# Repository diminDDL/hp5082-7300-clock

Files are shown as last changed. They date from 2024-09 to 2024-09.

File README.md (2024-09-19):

# HP5082-7300 Clock

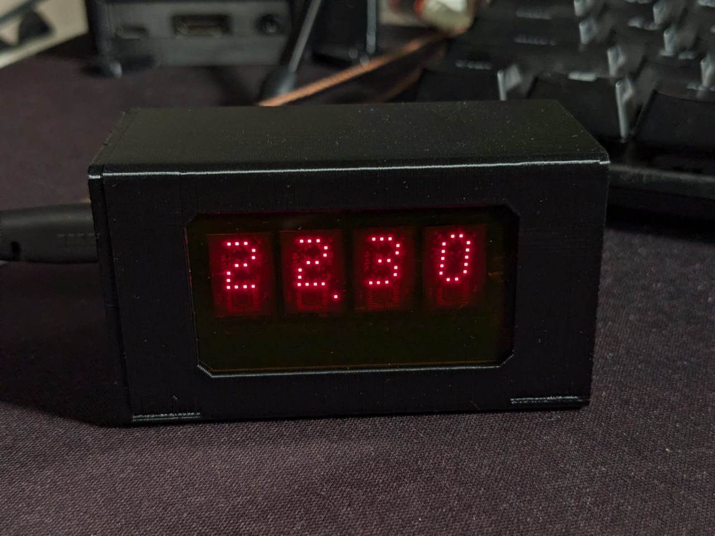
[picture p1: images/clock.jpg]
The finished clock


This repository contains the PlatformIO project for the Wemos D1 Mini based clock using the HP5082-7300 7-segment display. The repository also has the necessary 3D model files for the case. Since my case was designed around the protoboard I soldered the segments onto, it might not be compatible with your setup. Thus the Fusion 360 files as well as step files are included for you to modify.

## Features
- NTP time synchronization
- Timezone support
- DST support
- Web interface for configuration
- OTA updates*
 
*OTA updates are handled though the WiFiManager library, which requires you to upload a firmware file though the captive portal. You will need to remove the dummy OTA callback that is currently in the firmware for "security" reasons.

## Build instructions
### Hardware
- 1x Wemos D1 Mini
- 4x HP5082-7300 7-segment display
- 1x Button of any kind
- 1x 2k-100k pull-up resistor for the button
- 1x Thin sheet of plastic to protect the displays
- 2x 3.5M captive screws
- Protoboard, wires, etc.
- 3D printed case

#### Pinout
##### Segment Control Pins

These are the pins that select what to display on the display, the HP5082-7300 has it's own binary decoder and memory, meaning that we can wire all of these in parallel for all the segments and control the latching with the enable pins.

| Pin Number | Pin Name | Description |
|---|---|---|
| D1 | DIGIT_PIN_1 | Binary digit selection pin (LSB) |
| D2 | DIGIT_PIN_2 | Binary digit selection pin |
| D3 | DIGIT_PIN_4 | Binary digit selection pin |
| D4 | DIGIT_PIN_8 | Binary digit selection pin (MSB) |

##### Display Enable Pins

Each display in the 4x HP5082-7300 array is enabled individually using the following pins:

| Pin Number | Pin Name | Description |
|---|---|---|
| D8 | DIGIT_0_EN_PIN | Enables the digit 0 |
| D7 | DIGIT_1_EN_PIN | Enables the digit 1 |
| D6 | DIGIT_2_EN_PIN | Enables the digit 2 |
| D5 | DIGIT_3_EN_PIN | Enables the digit 3 |

##### Dot Pin

The dot is a decimal point that is pulsed once a second, it connected to the digit that separates the hours and minutes. Connect this to `D0`.

##### Button Pin

The button is connected to `A0` and it pulled up to 3.3V externally using the resistor. The button shorts the pin to ground when pressed. The analog pin is used because there were not enough pins on the Wemos D1 Mini to use a separate pin for the button.

### Software
1. Clone/Download the repository
2. Open the HP50827300Clock in [PlatformIO](https://marketplace.visualstudio.com/items?itemName=platformio.platformio-ide)
3. Change the `DST_REGION` to one of the following:
`DST_EUROPE`,
`DST_NORTH_AMERICA`,
`DST_AUSTRALIA`,
`DST_SOUTH_AMERICA`
4. Build and upload the firmware to the Wemos D1 Mini

## Usage
After the code is uploaded the clock will display `----` and create a WiFi network called `LED Clock Config`. You can use your phone to connect to this network and it should automatically open a configuration page.
- First, enter the `Setup` menu and configure your timezone and DST preference. You can leave the NTP server as is. Click `Save` and it should show a confirmation message.

If the page does not put you back to the main page you can manually go back until you reach it.

- Next enter the `Configure WiFi` menu (it will take a bit to open since it is scanning for networks). Click the network name you'd like to connect to and enter the password. Click `Save` and it should show a confirmation message.

Within a minute the clock should connect to the network and start displaying the time. If it doesn't the clock will keep displaying `----` and re-open the `LED Clock Config` access point for you to try configuring it again.

### Resetting

As mentioned before, when the clock can't connect to the WiFi network it will re-open the `LED Clock Config` access point. But if you want to reset it manually you can press and hold the button for 5 seconds. The clock will display an animation while you are holding the button and show `----` once it is reset, you can let go of the button at that point, and now use the access point to configure it again.

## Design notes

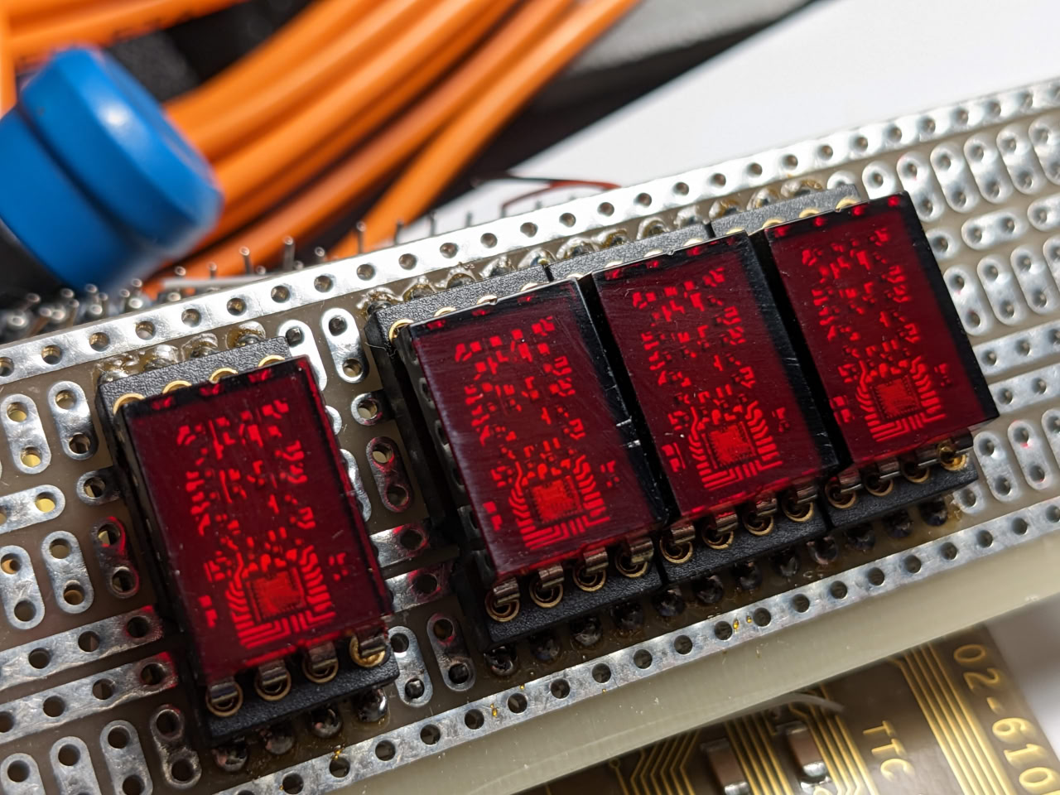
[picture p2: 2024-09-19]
images/panel.jpg

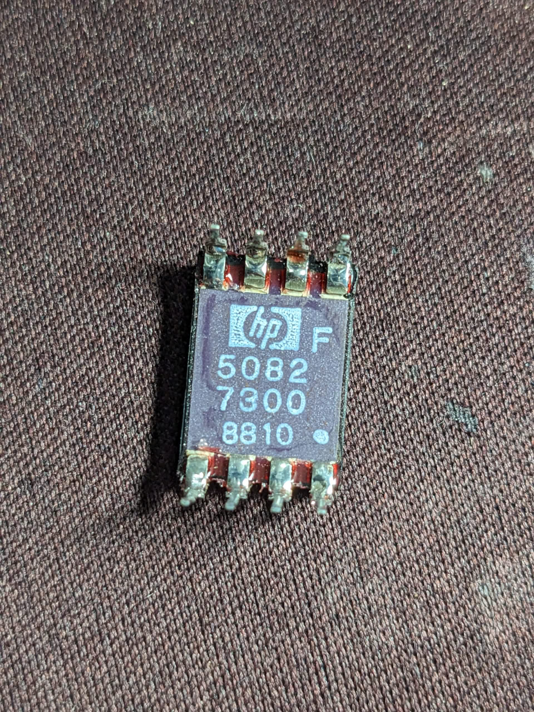
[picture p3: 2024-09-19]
images/indicator.jpg

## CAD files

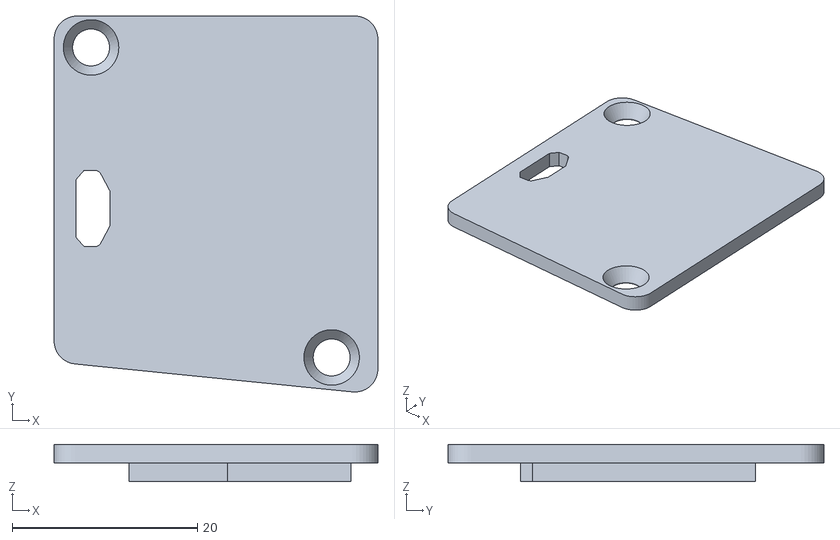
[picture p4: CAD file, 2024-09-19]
3D/clockCover.stl
35.0 x 40.6 x 4.00

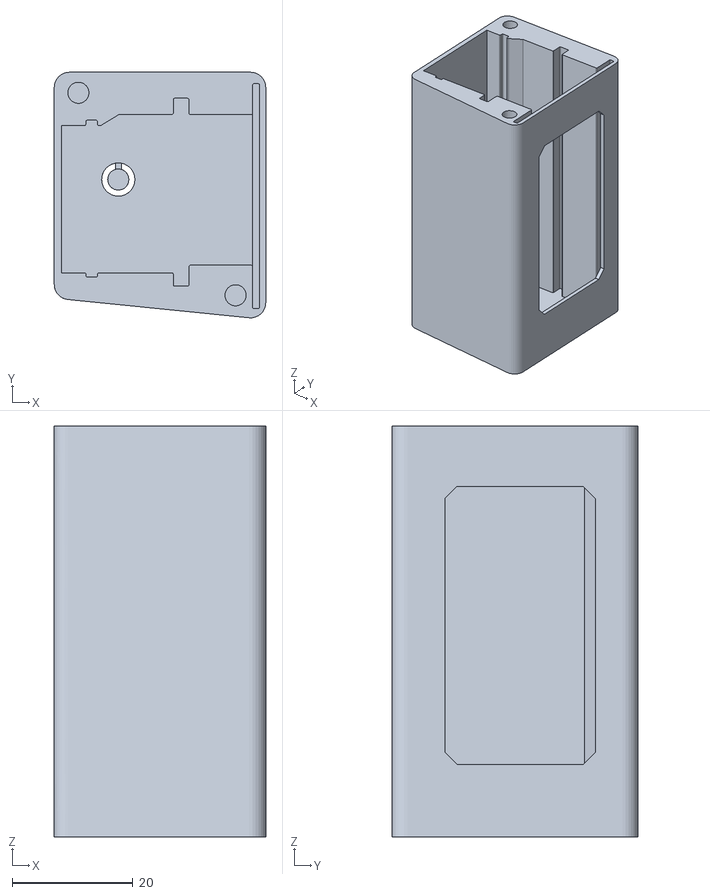
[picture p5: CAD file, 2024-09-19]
3D/clockCase.stl
35.0 x 40.6 x 68.0

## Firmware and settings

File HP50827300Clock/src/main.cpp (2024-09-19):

#include <Arduino.h>
#include <WiFiManager.h>
#include <NTPClient.h>
#include <WiFiUdp.h>
#include <EEPROM.h>

#define DIGIT_PIN_1 D1 
#define DIGIT_PIN_2 D2
#define DIGIT_PIN_4 D3
#define DIGIT_PIN_8 D4

#define DIGIT_0_EN_PIN D8
#define DIGIT_1_EN_PIN D7
#define DIGIT_2_EN_PIN D6
#define DIGIT_3_EN_PIN D5

#define DOT_PIN D0

#define DST_REGION DST_EUROPE

// settings struct
struct Settings {
    int8_t timezoneOffset;
    bool daylightSaving;
    char ntpServer[128];
} settings;

// stuct to hold the current display state
struct Display {
    uint8_t digits[4];
    uint8_t selectedDigit;
    bool dot;
} dispState;

// helper function to select the digit to display
void selectDigit(uint8_t digit);

// helper function to set the value of the 4-bit display
void setVal(uint8_t val);

// set a value to a specific digit
void setDigit(uint8_t digit, uint8_t val);

// clear all digits
void clearAll();

// set the dot state
void writeDot(bool state);

// write the time to the display
void writeTime(uint8_t hour, uint8_t minute);

// initialize the pins
void initPins();

// check if daylight saving time is active
bool checkDST(unsigned long epoch, uint region = 0, int8_t timezone = 0);

// wifi manager
WiFiManager wm;
// custom fields
WiFiManagerParameter tz_field;
WiFiManagerParameter dst_field;
WiFiManagerParameter ntp_server_field;
// ntp client
WiFiUDP ntpUDP;
NTPClient timeClient(ntpUDP);

// callback for the save settings event
void saveParamCallback();

// reset the ESP
void reset();

void setup() {
    WiFi.mode(WIFI_STA);

    Serial.begin(115200);

    EEPROM.begin(1024);

    uint8_t check = 0;
    check = EEPROM.read(512);

    Serial.println("EEPROM check:");
    Serial.println(check);

    if(check == 0xFF){
        Serial.println("EEPROM is empty, writing default settings");
        settings.timezoneOffset = 2;
        settings.daylightSaving = true;
        strcpy(settings.ntpServer, "pool.ntp.org");
        EEPROM.put(256, settings);
        EEPROM.write(512, 0);
        EEPROM.commit();
        reset();
    }else{
        EEPROM.get(256, settings);
        Serial.println("EEPROM is not empty, reading settings");
        Serial.println(settings.timezoneOffset);
        Serial.println(settings.daylightSaving);
        Serial.println(settings.ntpServer);
    }

    initPins();
    setDigit(0, 13);
    setDigit(1, 13);
    setDigit(2, 13);
    setDigit(3, 13);

    // Can be used to reset settings for debugging
    // wm.resetSettings();

    wm.setConfigPortalBlocking(false);
    wm.setConnectTimeout(15);

    // timezone offset
    const char* tz_input_str = "<br/><label for='tzfield'>Timezone Offset:</label><br><input type='number' name='tzfield' value='0' min='-12' max='14'>";
    new (&tz_field) WiFiManagerParameter(tz_input_str);

    // daylight saving time
    const char* dst_checkbox_str = "<br/><label for='dstfield'>Daylight Saving Time:</label><br><input type='radio' name='dstfield' value='1' checked> ON<br><input type='radio' name='dstfield' value='0'> OFF<br>";
    new (&dst_field) WiFiManagerParameter(dst_checkbox_str);

    // ntp server
    const char* ntp_server_input_str = "<br/><label for='ntpserverfield'>NTP Server:</label><br><input type='text' name='ntpserverfield' value='pool.ntp.org'>";
    new (&ntp_server_field) WiFiManagerParameter(ntp_server_input_str);

    wm.addParameter(&tz_field);
    wm.addParameter(&dst_field);
    wm.addParameter(&ntp_server_field);
    wm.setSaveParamsCallback(saveParamCallback);
    
    // set the order of the menu items
    // std::vector<const char *> menu = {"wifi","param","sep","info","restart","exit"};
    std::vector<const char *> menu = {"wifi","param","sep","exit"};
    wm.setMenu(menu);

    // set dark theme
    wm.setClass("invert");

    wm.setPreOtaUpdateCallback([](){
        Serial.println("Dummy OTA callback to prevent OTA updates. Resetting...");
        reset();
    });

    // configure the NTP client
    timeClient.begin();
    timeClient.setUpdateInterval(600000);    // once every 10 minutes

    // set the timezone offset and NTP server
    timeClient.setTimeOffset(3600 * settings.timezoneOffset);
    timeClient.setPoolServerName(settings.ntpServer);

    // try to connect to wifi
    if(wm.autoConnect("LED Clock Config")) {
        timeClient.update();
    }
}

// helper function to read parameter from server, for customhmtl input
String getParam(String name){
  String value;
  if(wm.server->hasArg(name)) {
    value = wm.server->arg(name);
  }
  return value;
}

void saveParamCallback(){
    Serial.println("[CALLBACK] saveParamCallback fired");
    Serial.println("PARAM tzfield = " + getParam("tzfield"));
    Serial.println("PARAM dstfield = " + getParam("dstfield"));
    Serial.println("PARAM showdatefield = " + getParam("showdatefield"));
    Serial.println("PARAM ntpserverfield = " + getParam("ntpserverfield"));

    settings.timezoneOffset = getParam("tzfield").toInt();
    settings.daylightSaving = (bool)getParam("dstfield").toInt();
    strcpy(settings.ntpServer, getParam("ntpserverfield").c_str());

    // save settings to EEPROM
    EEPROM.put(256, settings);
    EEPROM.write(512, 0);
    EEPROM.commit();

    timeClient.setTimeOffset(3600 * settings.timezoneOffset);
    timeClient.setPoolServerName(settings.ntpServer);
}

bool canUpdate = false;
bool firstStart = true;
bool forceUpdate = false;
bool dst = false;
unsigned long lastMillis = 0;

uint16_t adc_counter = 0;
uint8_t digit = 0;

int8_t hour = 0;
int8_t minute = 0;
int8_t second = 0;
int8_t lastSecond = 0;

int8_t testHour = 0;
int8_t testMinute = 0;
int8_t testSecond = 0;

void loop() {
    wm.process();

    // check if we are connected to wifi
    if(WiFi.status() == WL_CONNECTED && !canUpdate) {
        canUpdate = true;
    }

    // we don't need to update more often than once per second
    if(canUpdate && millis() - lastMillis > 1000) {

        if(timeClient.getEpochTime() == 0){
            forceUpdate = true;
        }

        lastMillis = millis();
        if(forceUpdate){
            timeClient.forceUpdate();
            forceUpdate = false;
            firstStart = true;
        }else{
            timeClient.update();
        }

        if(settings.daylightSaving){
            dst = checkDST(timeClient.getEpochTime(), settings.timezoneOffset);
            timeClient.setTimeOffset(3600 * (settings.timezoneOffset + dst));
            timeClient.update();
        }

        if(timeClient.isTimeSet()){
            testHour = timeClient.getHours();
            testMinute = timeClient.getMinutes();
            testSecond = timeClient.getSeconds();
        }
    }

    // checks for the time to be consistent (common issue with NTP)
    if(timeClient.isTimeSet() &&
    (((testHour - hour == 1 || testHour - hour == 0 || testHour - hour == -23) &&
    (testMinute - minute == 1 || testMinute - minute == 0 || testMinute - minute == -59)) || 
    firstStart)) {
        hour = testHour;
        minute = testMinute;
        second = testSecond;
        firstStart = false;
        forceUpdate = false;
    }else if(timeClient.isTimeSet() && !firstStart){    // if the time range constraints failed we force an NTP update
        // this logic is here because sometimes NTP returns all zeroes even when timeClient.isTimeSet() reports true
        forceUpdate = true;
    }

    // write the time to the display
    if(canUpdate && adc_counter == 0){
        writeTime(hour, minute);
    }else if(adc_counter == 0){
        writeDot(true);
        setDigit(0, 13);
        setDigit(1, 13);
        setDigit(2, 13);
        setDigit(3, 13);
    }

    // the second dot
    if(second != lastSecond) {
        writeDot(second % 2);
        lastSecond = second;
    }

    // the reset button functionality
    while(analogRead(A0) <= 50){
        adc_counter++;
        if(adc_counter % 8 == 0){
            digit++;
            if(digit > 3){
                digit = 0;
            }
        }

        for(uint8_t i = 0; i < 4; i++){
            if(i == digit){
                setDigit(i, 13);
            }else{
                setDigit(i, 12);
            }
        }
        

        // reset the ESP if the button is pressed for more than ~5 seconds
        if (adc_counter > 50) {
            adc_counter = 0;
            reset();
        }
        delay(100);
    }
    adc_counter = 0;
    
    // rate limit the loop
    delay(100);
}


void selectDigit(uint8_t digit) {
    digitalWrite(DIGIT_0_EN_PIN, digit != 0);
    digitalWrite(DIGIT_1_EN_PIN, digit != 1);
    digitalWrite(DIGIT_2_EN_PIN, digit != 2);
    digitalWrite(DIGIT_3_EN_PIN, digit != 3);
    dispState.selectedDigit = digit;
}

void setVal(uint8_t val) {
    digitalWrite(DIGIT_PIN_1, val & 0x01);
    digitalWrite(DIGIT_PIN_2, val & 0x02);
    digitalWrite(DIGIT_PIN_4, val & 0x04);
    digitalWrite(DIGIT_PIN_8, val & 0x08);
    dispState.digits[dispState.selectedDigit] = val;
}

void setDigit(uint8_t digit, uint8_t val) {
    selectDigit(digit);
    setVal(val);
}

void clearAll(){
    digitalWrite(DIGIT_0_EN_PIN, LOW);
    digitalWrite(DIGIT_1_EN_PIN, LOW);
    digitalWrite(DIGIT_2_EN_PIN, LOW);
    digitalWrite(DIGIT_3_EN_PIN, LOW);
    digitalWrite(DIGIT_PIN_1, HIGH);
    digitalWrite(DIGIT_PIN_2, HIGH);
    digitalWrite(DIGIT_PIN_4, HIGH);
    digitalWrite(DIGIT_PIN_8, HIGH);
    digitalWrite(DOT_PIN, HIGH);
    digitalWrite(DIGIT_0_EN_PIN, HIGH);
    digitalWrite(DIGIT_1_EN_PIN, HIGH);
    digitalWrite(DIGIT_2_EN_PIN, HIGH);
    digitalWrite(DIGIT_3_EN_PIN, HIGH);
    for (int i = 0; i < 4; i++) {
        dispState.digits[i] = 0;
    }
    dispState.dot = false;
}

void writeDot(bool state) {
    setDigit(1, dispState.digits[1]);   // the dot is at digit 1
    digitalWrite(DOT_PIN, !state);
    dispState.dot = !state;
    setDigit(dispState.selectedDigit, dispState.digits[dispState.selectedDigit]);   // restore the selected digit
}

void writeTime(uint8_t hour, uint8_t minute) {
    setDigit(0, hour / 10);
    setDigit(1, hour % 10);
    setDigit(2, minute / 10);
    setDigit(3, minute % 10);
}

void initPins(){
    pinMode(DIGIT_PIN_1, OUTPUT);
    pinMode(DIGIT_PIN_2, OUTPUT);
    pinMode(DIGIT_PIN_4, OUTPUT);
    pinMode(DIGIT_PIN_8, OUTPUT);
    pinMode(DOT_PIN, OUTPUT);
    pinMode(DIGIT_0_EN_PIN, OUTPUT);
    pinMode(DIGIT_1_EN_PIN, OUTPUT);
    pinMode(DIGIT_2_EN_PIN, OUTPUT);
    pinMode(DIGIT_3_EN_PIN, OUTPUT);
}

void reset(){
    wm.resetSettings();
    delay(100);
    ESP.restart();
}

enum DST_REGIONS {
    DST_EUROPE = 0,
    DST_NORTH_AMERICA = 1,
    DST_AUSTRALIA = 2,
    DST_SOUTH_AMERICA = 3
};

// Helper function to calculate the day of the week for a given epoch
// 0 = Sunday, 1 = Monday, ..., 6 = Saturday
int dayOfWeek(unsigned long epoch) {
    return (epoch / 86400L + 4) % 7;
}

// Helper function to calculate the number of days since January 1st, 1970
unsigned long daysSinceEpoch(unsigned long epoch) {
    return epoch / 86400L;
}

// Helper function to get the current month from the epoch
int getMonth(unsigned long epoch, int8_t timezone) {
    unsigned long days = daysSinceEpoch(epoch + timezone * 3600);
    int year = 1970;
    int month = 0;
    while (days >= 365) {
        days -= (year % 4 == 0 && (year % 100 != 0 || year % 400 == 0)) ? 366 : 365;
        year++;
    }
    static const int daysInMonth[] = { 31, 28, 31, 30, 31, 30, 31, 31, 30, 31, 30, 31 };
    for (month = 0; month < 12; month++) {
        int dim = daysInMonth[month];
        if (month == 1 && (year % 4 == 0 && (year % 100 != 0 || year % 400 == 0))) {
            dim = 29;
        }
        if (days < dim) break;
        days -= dim;
    }
    return month + 1;
}

// Helper function to get the current day of the month
int getDayOfMonth(unsigned long epoch, int8_t timezone) {
    unsigned long days = daysSinceEpoch(epoch + timezone * 3600);
    int year = 1970;
    int month = 0;
    while (days >= 365) {
        days -= (year % 4 == 0 && (year % 100 != 0 || year % 400 == 0)) ? 366 : 365;
        year++;
    }
    static const int daysInMonth[] = { 31, 28, 31, 30, 31, 30, 31, 31, 30, 31, 30, 31 };
    for (month = 0; month < 12; month++) {
        int dim = daysInMonth[month];
        if (month == 1 && (year % 4 == 0 && (year % 100 != 0 || year % 400 == 0))) {
            dim = 29;
        }
        if (days < dim) break;
        days -= dim;
    }
    return days + 1;
}

// Main function to check if DST is active
bool checkDST(unsigned long epoch, uint region, int8_t timezone) {
    int month = getMonth(epoch, timezone);
    int day = getDayOfMonth(epoch, timezone);
    int dow = dayOfWeek(epoch);

    switch (region) {
        case DST_EUROPE:
            // DST in Europe: Last Sunday of March to Last Sunday of October
            if ((month > 3 && month < 10) || 
                (month == 3 && (day - dow) >= 25) || 
                (month == 10 && (day - dow) <= 24)) {
                return true;
            }
            return false;

        case DST_NORTH_AMERICA:
            // DST in North America: Second Sunday of March to First Sunday of November
            if ((month > 3 && month < 11) || 
                (month == 3 && (day - dow) >= 8) || 
                (month == 11 && (day - dow) <= 0)) {
                return true;
            }
            return false;

        case DST_AUSTRALIA:
            // DST in Australia: First Sunday of October to First Sunday of April
            if ((month > 10 || month < 4) || 
                (month == 10 && (day - dow) >= 1) || 
                (month == 4 && (day - dow) <= 0)) {
                return true;
            }
            return false;

        case DST_SOUTH_AMERICA:
            // DST in Chile (example for South America): First Sunday of September to First Sunday of April
            if ((month > 9 || month < 4) || 
                (month == 9 && (day - dow) >= 1) || 
                (month == 4 && (day - dow) <= 0)) {
                return true;
            }
            return false;

        default:
            return false;
    }
}
